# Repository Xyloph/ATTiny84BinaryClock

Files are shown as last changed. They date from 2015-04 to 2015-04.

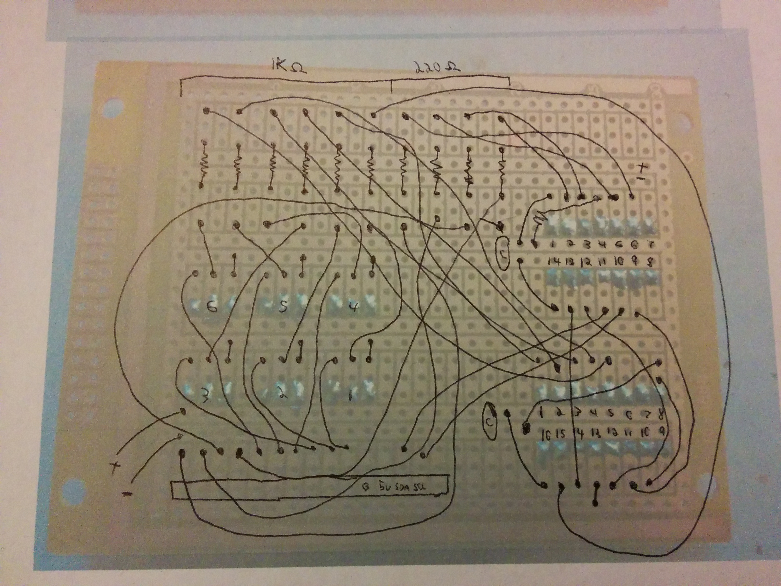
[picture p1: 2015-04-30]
perfboard-connections.jpg

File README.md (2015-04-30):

# ATTiny84BinaryClock

This project's goal is to create a binary clock using an ATTiny84 along with a DS1307 RTC.

Here's a quick video of the final product: https://www.youtube.com/watch?v=mD4HjlXqTbA

Disclaimer: I'm awful at choosing the proper location of stuff on a board :)

## Parts

- ATTiny84
- 74HC595N 8-bit Shift Register
- 6x 2N2222A PNP Transistors
- 5V Power Supply
- Bunch of wires
- 20 blue LEDs
- A perfboard big enough to fit everything but small enough to fit in the enclosure.
- A plastic box.
- 6x 1k Ω resistors for the transistors (larger values can be used).
- 4x 220 Ω resistors to limit the power provided to a LED.
- DS1307 Real Time Clock kit (I bought one from Adafruit).

## Things to know

Using the real time clock is kinda painful with the ATTiny84 because that microcontroller does not support the I2C protocol. Because of this, I've used the I2CMaster v2 which can be found here: https://forums.adafruit.com/viewtopic.php?f=25&t=13722&start=0 . I modified it to remove support for the real I2C implementation which did not compile if the board was set to ATTiny.

Make sure you verify your pin numbers in the code, I changed them at some point because my schematic was initially wrong. The pen and paper version is the most accurate of the final result.

I also used the Time library found on Arduino.cc. It is useful because it provides a cache of the time, so it doesn't have to be retrieved off the RTC every loop.

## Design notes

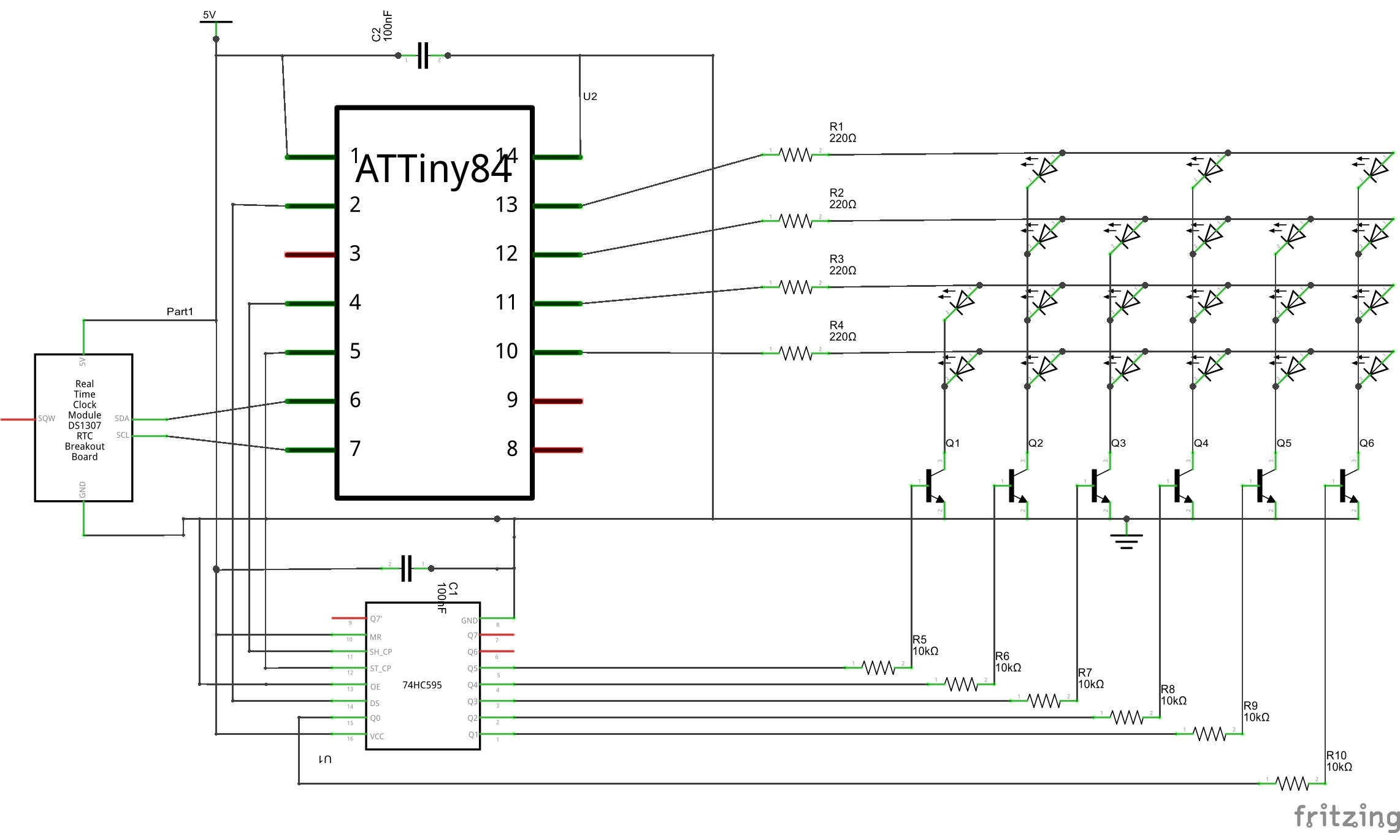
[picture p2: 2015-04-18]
schematic_schem.jpg

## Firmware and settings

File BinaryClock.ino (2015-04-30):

/* *
 * Binary Clock using RTC, 74HC595N and 6 2N2222A NPN
 */

#include <Time.h>
#include <I2cMaster.h>

#define SDA_PIN 3 // Used for RTC
#define SCL_PIN 4 // Used for RTC

#define LATCH   1 // Used for Shift Register
#define CLOCK   2 // Used for Shift Register
#define DATA    0 // Used for Shift Register

#define LED1    7 // Led out on ATTiny84
#define LED2    8 // Led out on ATTiny84
#define LED4    9 // Led out on ATTiny84
#define LED8   10 // Led out on ATTiny84

#define LED1V  1  // Constant used for LED bit  
#define LED2V  2  // Constant used for LED bit
#define LED4V  4  // Constant used for LED bit
#define LED8V  8  // Constant used for LED bit

// i2c 8-bit address for DS1307. low bit is read/write
#define DS1307ADDR 0XD0

// select software or hardware i2c
#define USE_SOFT_I2C 1

// Grounds byte used for bit shifting
byte grounds;

// SoftI2C used for reading
SoftI2cMaster rtc(SDA_PIN, SCL_PIN);

// Buffer for storing data from DS1307
uint8_t buf[8];

void setup()  
{
  setSyncProvider(getTime);   // the function to get the time from the RTC
  
  // Set output pins to, well, output mode.
  pinMode(LATCH, OUTPUT);
  pinMode(CLOCK, OUTPUT);
  pinMode(DATA, OUTPUT);
  pinMode(LED1, OUTPUT);
  pinMode(LED2, OUTPUT);
  pinMode(LED4, OUTPUT);
  pinMode(LED8, OUTPUT);
  
  // Remove all the LEDS lit
  clearLeds();
}

void loop()
{
  // Set the initial ground byte, open to tens of hour.
  grounds = 0b10000000;
  
  // Display magic.
  time_t time = now();
  
  processUnits(hour(time), false);
  processUnits(minute(time), true);
  processUnits(second(time), true);
}

// Open the grounds requested through the shift register.
void updateGrounds()
{
  digitalWrite(LATCH, LOW);
  shiftOut(DATA, CLOCK, LSBFIRST, grounds);
  digitalWrite(LATCH, HIGH);
}

// Set all LED pins low to avoid weird multiplexing results.
void clearLeds()
{
  digitalWrite(LED1, LOW);
  digitalWrite(LED2, LOW);
  digitalWrite(LED4, LOW);
  digitalWrite(LED8, LOW);
}

// Shows a number by showing the tens then the units.
// Takes care of changing the grounds.
// If shift is false, do not shift grounds initially. Used for Hours.
void processUnits(uint8_t nbr, boolean shift)
{
  if (shift)
  {
    // Shift grounds
    grounds = grounds >> 1;
  }
  
  // Update the grounds
  updateGrounds();
  
  // Extract the tens and units.  
  uint8_t nbr1 = nbr % 10;
  uint8_t nbr10 = nbr / 10;
  
  digitalWrite(LED4, (nbr10 & LED4V) == LED4V ? HIGH : LOW);
  digitalWrite(LED2, (nbr10 & LED2V) == LED2V ? HIGH : LOW);
  digitalWrite(LED1, (nbr10 & LED1V) == LED1V ? HIGH : LOW);
  delay(1);
  
  // Remove all the LEDS lit
  clearLeds();
  
  // Shift grounds
  grounds = grounds >> 1;
  updateGrounds();
  
  digitalWrite(LED8, (nbr1 & LED8V) == LED8V ? HIGH : LOW);
  digitalWrite(LED4, (nbr1 & LED4V) == LED4V ? HIGH : LOW);
  digitalWrite(LED2, (nbr1 & LED2V) == LED2V ? HIGH : LOW);
  digitalWrite(LED1, (nbr1 & LED1V) == LED1V ? HIGH : LOW);
  delay(1);
  
  // Clear LEDs again
  clearLeds();
}

// Convert Binary Coded Decimal (BCD) to Decimal
uint8_t bcd2dec(uint8_t num)
{
  return ((num/16 * 10) + (num % 16));
}

//Read 'count' bytes from the DS1307 starting at 'address'
uint8_t readDS1307(uint8_t address, uint8_t *buf, uint8_t count) {
  // issue a start condition, send device address and write direction bit
  if (!rtc.start(DS1307ADDR | I2C_WRITE)) return false;

  // send the DS1307 address
  if (!rtc.write(address)) return false;

  // issue a repeated start condition, send device address and read direction bit
  if (!rtc.restart(DS1307ADDR | I2C_READ))return false;

  // read data from the DS1307
  for (uint8_t i = 0; i < count; i++) {

    // send Ack until last byte then send Ack
    buf[i] = rtc.read(i == (count-1));
  }

  // issue a stop condition
  rtc.stop();
  return true;
}

// Create a time object for the Time lib, allowing calls to now(), hour(), etc.
time_t getTime()
{
  tmElements_t tm;
  
  if (readDS1307(0, buf, 8))
  {
    // read successful
    tm.Second = bcd2dec(buf[0]);
    tm.Minute = bcd2dec(buf[1]);
    tm.Hour = bcd2dec(buf[2]);
    tm.Wday = bcd2dec(buf[3]);
    tm.Day = bcd2dec(buf[4]);
    tm.Month = bcd2dec(buf[5]);
    tm.Year = bcd2dec(buf[6]);
  }
  
  return(makeTime(tm));
}

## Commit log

2015-04-18 Adding fritzing file
    [schematic.fzz]
2015-04-18 adding jpg of schematic
2015-04-19 template done
    [schematic.fzz]
2015-04-30 Added arduino sketch, dependancies and info will follow
2015-04-30 text update and perfboard schematic
